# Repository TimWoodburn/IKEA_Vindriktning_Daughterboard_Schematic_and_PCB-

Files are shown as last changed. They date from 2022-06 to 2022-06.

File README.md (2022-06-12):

# IKEA_Vindriktning_Daughterboard_Schematic_and_PCB

## Prelude - design choices before this project.
After reading about the IKEA sensor in Hackaday <https://hackaday.com/2021/08/13/hacked-ikea-air-quality-sensor-gets-custom-pcb/> I embarked on implementing on my favourite Wifi connected microcontroller ESP8266 with a view to adding additional sensors.  My usual preference is to roll-my-own, but during my research I became aware of a couple of implementations that utilized Tasmota.  This is an ideal platform to satisfy this requirement.  Web front end, MQTT ready, community maintained and includes the peripherals I was interested in; namely BME280 and LDR and the Ikea particulate sensor.  

This project is an adoptation based on Lond's Hackaday.io project, https://hackaday.io/project/181195-ikea-vindriktning-pcb and
Catalin Sanda who provided their schematics, https://hackaday.io/project/184282-ikea-vindriktning-daughterboard  

Blakadder has a nice write up.  The Tasmota setup is applicable to this project https://blakadder.com/vindriktning-tasmota/

If you dont wish to use Tasmota, checkout Hypfer's implements decoding of the Ikea sensor directly https://github.com/Hypfer/esp8266-vindriktning-particle-sensor

## Project Details

This project adds BME280 and Light Dependent resistor and uses Catalin Sanda's Tasmota binary.

The project uses the following ESP8266 ports:
- GPIO 4 for the Ikea particulate sensor input
- GPIO 1 for FTDI TXD
- GPIO 3 for FTDI RXD
- GPIO 12 for I2C SCL
- GPIO 14 for I2C SDA
- ADC for LDR input

## IKEA Vindriktning Daughterboard Schematic

A slight modification of Catalin Sanda's design on <https://hackaday.io/project/184282-ikea-vindriktning-daughterboard> which adds an input for a light dependent resistor into the ADC.  I have also chosen to use different inputs.  I also added the Molex picoblade sockets as suggested by Lond's project <https://hackaday.io/project/181195-ikea-vindriktning-pcb>.  The looms were challenging to work with and took some time to get right.  The Molex picoblade connectors look beautiful, but the crimps are tiny and practice makes perfect in getting them right.  If I did this project from scratch again, I would purchase pre-crimped plugs and then terminate the tails.  I bought a cheap crimp tool so I am sure the experience with the £200 ratcheted Molex crimp tool is far better, but it was too expensive for this project.

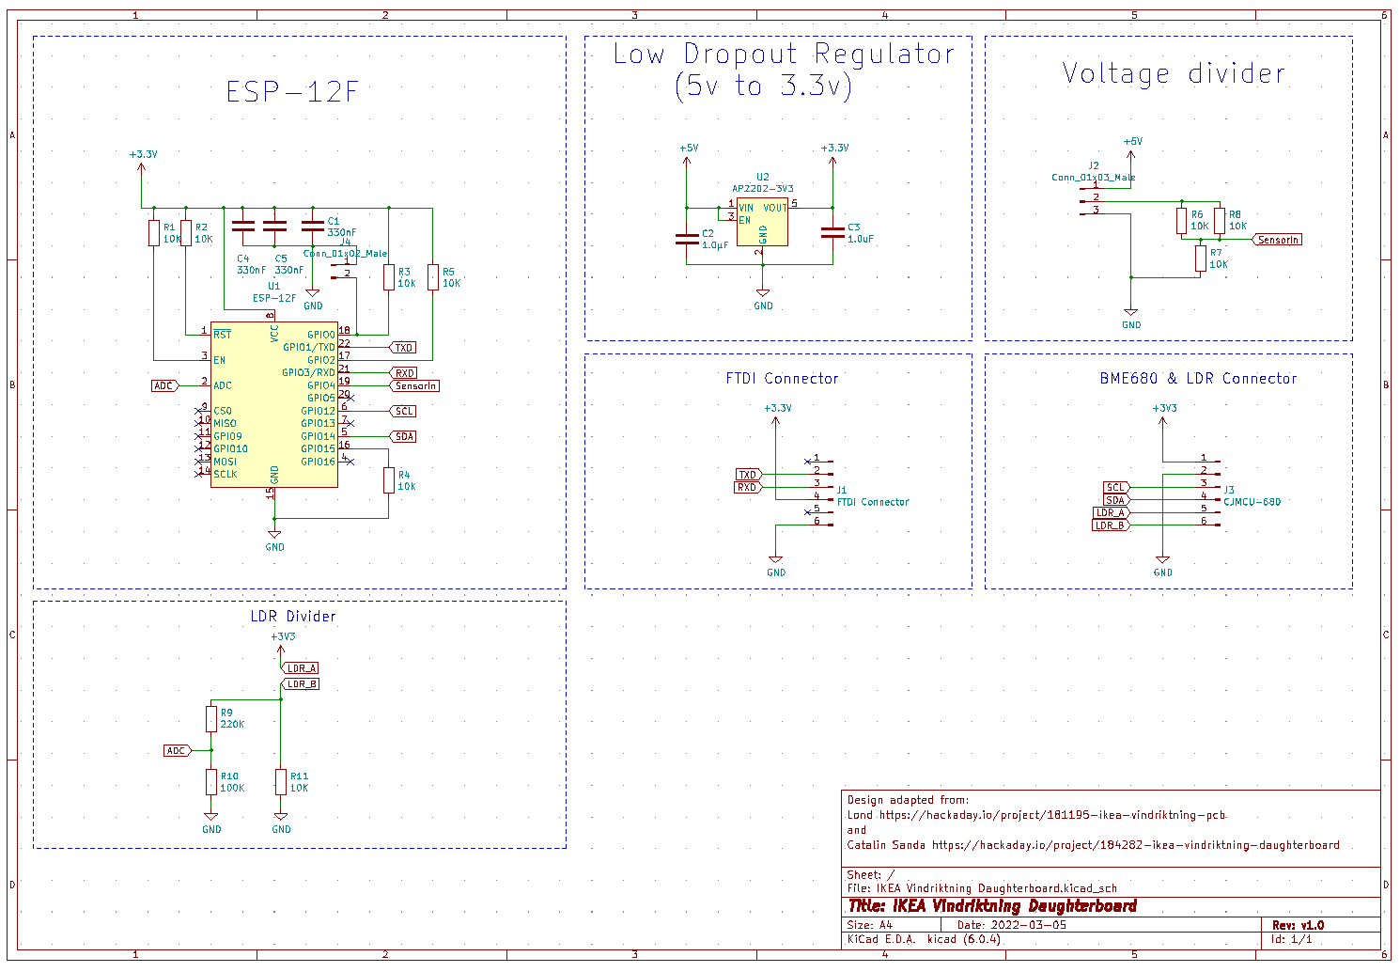
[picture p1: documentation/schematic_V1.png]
Schematic Schematic V1.0

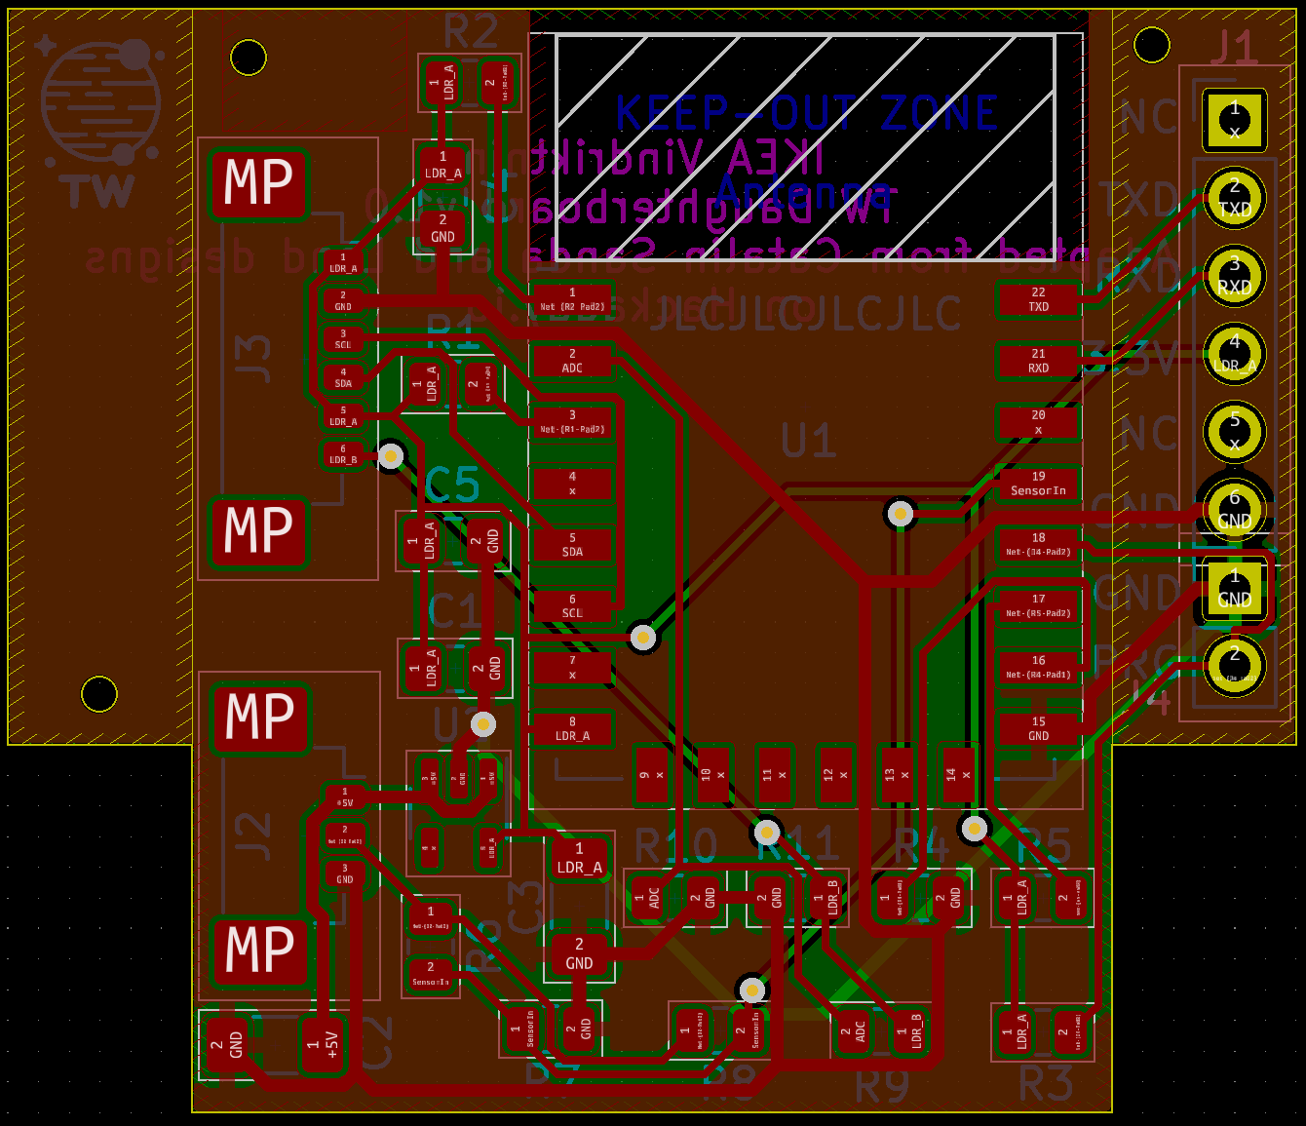
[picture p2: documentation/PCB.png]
PCB


## Modification of the IKEA Vindriktning PCB

The designers were very generous in making the board accessible to makers.  In order to use connect the daughterboard neatly, a 5 way Molex SMD socket should be soldered to the board (pictured on the LHS of the board).  As others have done in their solutions, it is possible to solder directly to the board.

The light dependent resistor is fitted to the fascia as pictured and terminals insulated.  I kept the BME280 loose to allow for placement away from the fascia in the other half of the enclosure.  
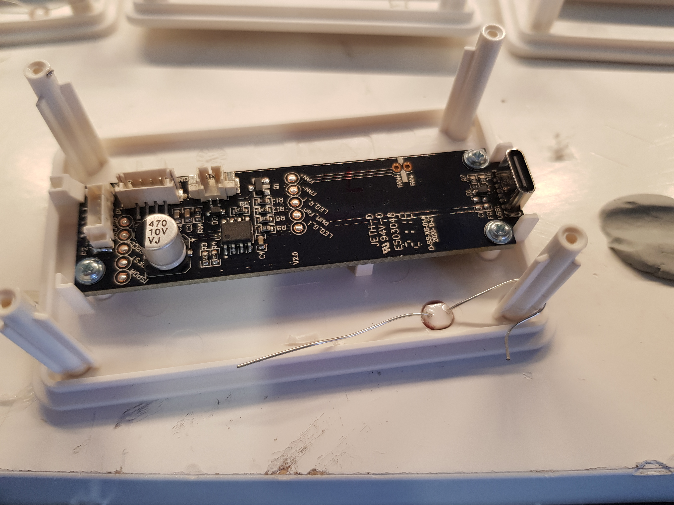
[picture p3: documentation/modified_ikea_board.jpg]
Modified Ikea board

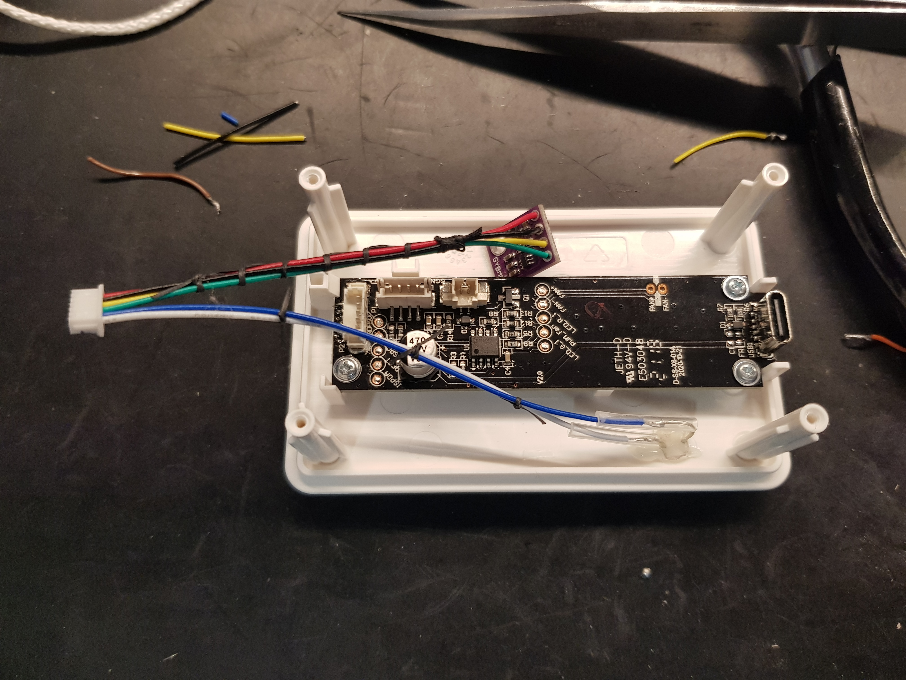
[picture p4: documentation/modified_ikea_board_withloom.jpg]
Modified Ikea board with loom


## Daughterboard

Pictured as received from JLCPCB.  Note R9 pictured reflects the BOM error which fitted a 2R2 resistor, rather than 220K0. The repo BOM has been corrected.
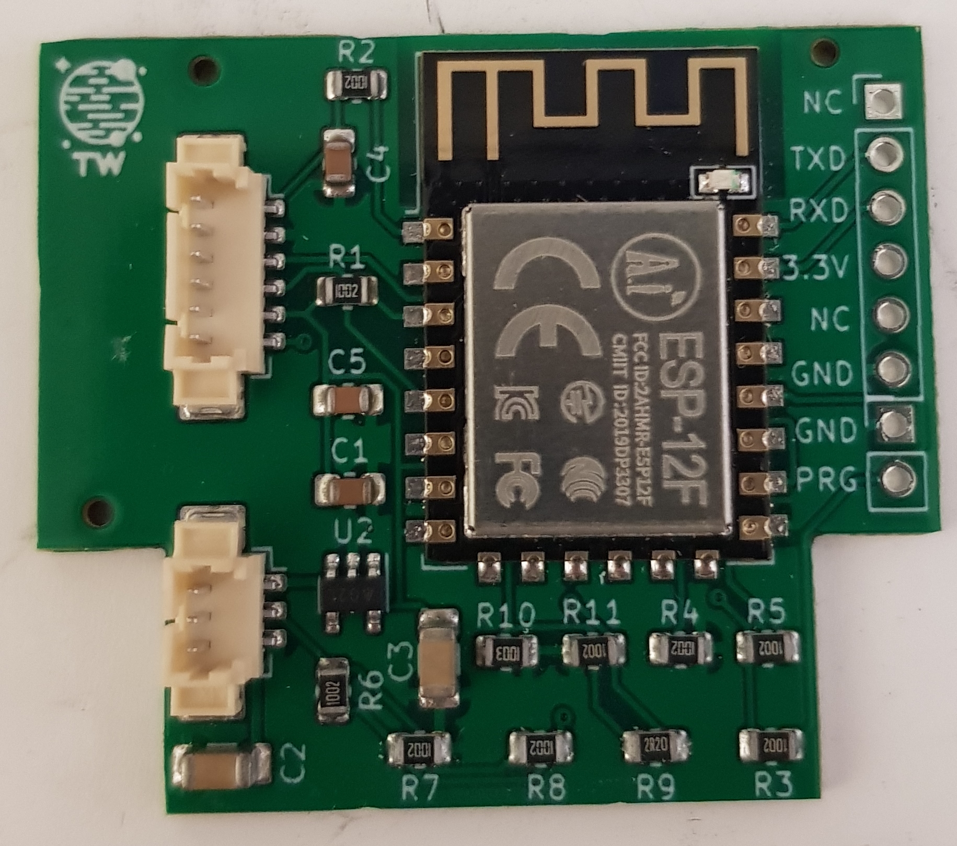
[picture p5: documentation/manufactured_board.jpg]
Final Assembled Board Final assembled board


I copied the Caralin's flashing method and will use the same method in future boards.  The PRG pin is shorted to ground away from the board.  I bought mine from AliExpress which seems to work quite well [LINK](https://www.aliexpress.com/item/1005001409579446.html)  I flashed the boards with Tazmotizer with the version that contains the Vindriktning peripheral.  Alternatively use [tasmota-allsensors unoffical build](https://github.com/tasmota/install/raw/main/firmware/unofficial/tasmota-allsensors.bin) although this is untested.  The version I used is within this repo.
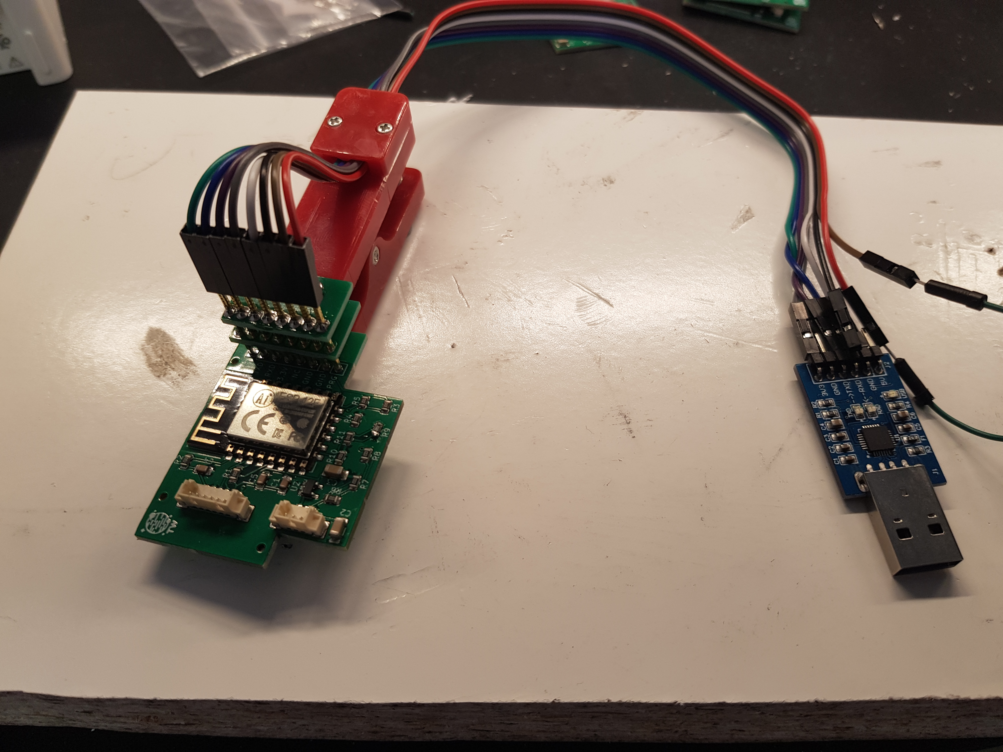
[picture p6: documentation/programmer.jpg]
Programming adaptor


The spring in the laced BME280 loom positions the board out of the way.  Once you have tested, you may wish to secure it.  The board itself slides behind the screw pillars.
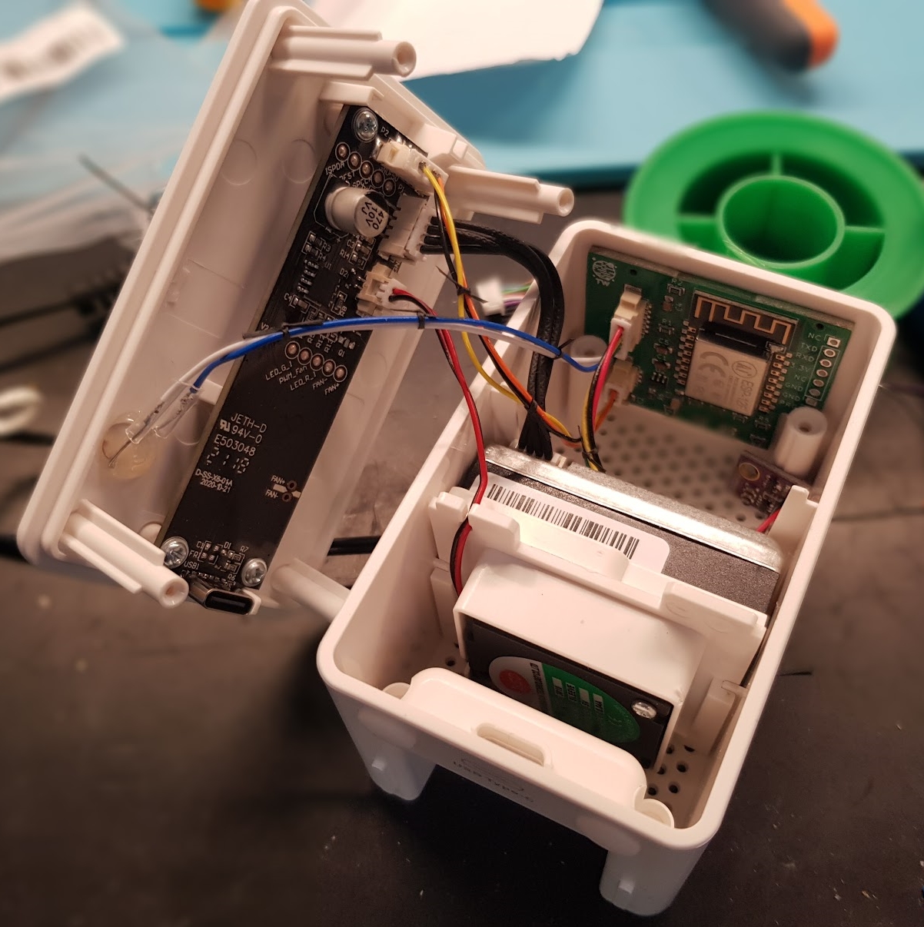
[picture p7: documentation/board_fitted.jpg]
Board fitted to Vindriktning


## Tasmota Setup 

Once fitted, configure the module as follows.
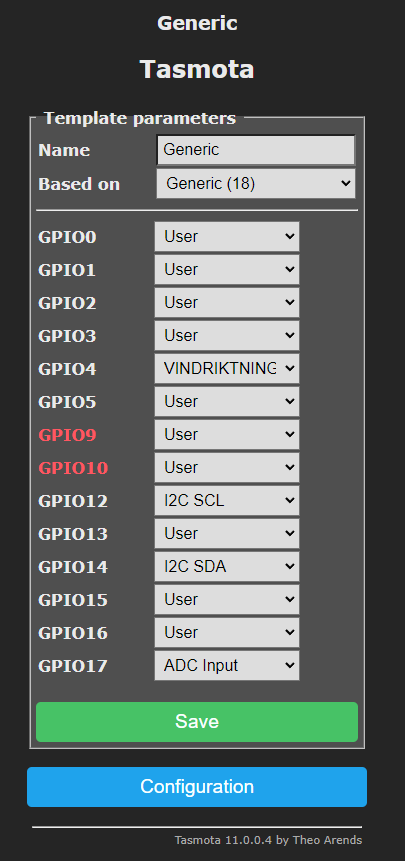
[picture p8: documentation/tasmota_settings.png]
Tasmota Settings


Which should generate a home page like this.
Tasmota Home Page TASMOTA home page

To change the device name, go to the "other options" page and set there.

## In use
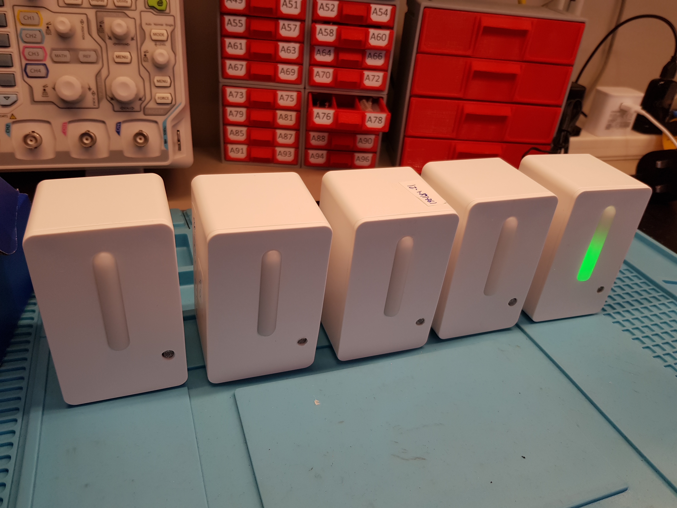
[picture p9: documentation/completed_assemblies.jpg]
Completed assemblies


I use mine with my other house sensors signalled with MQTT.  My MQTT setup uses Mosquitto and NODERED.  
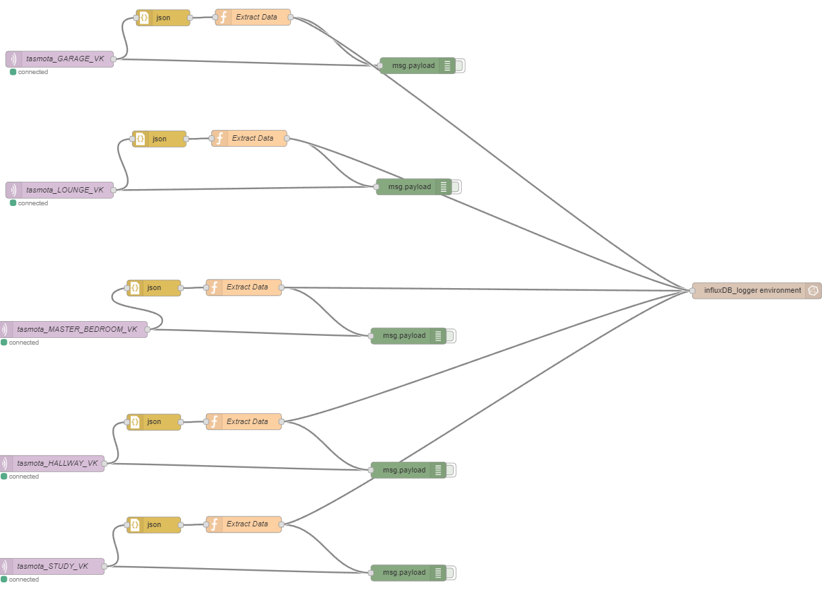
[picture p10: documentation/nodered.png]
NODE RED LAYOUT NODERED layout


The data is stored in an InfluxDB 3.x database and viewed on Grafana.  The garage peak is probably due to me sweeping up after completing this project!
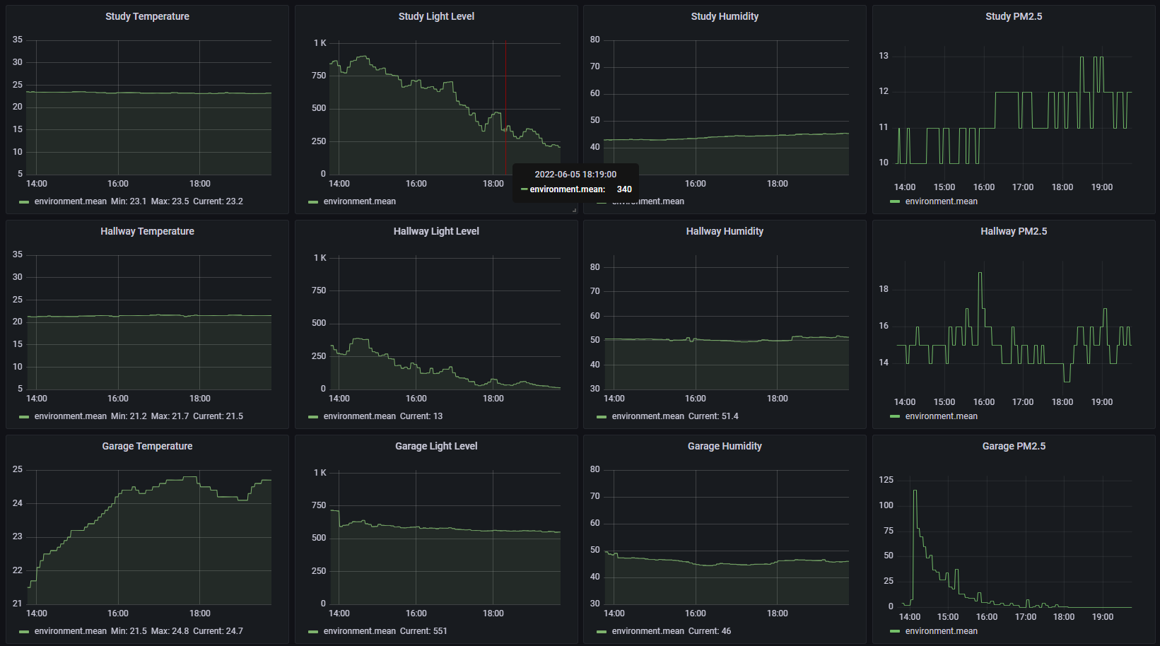
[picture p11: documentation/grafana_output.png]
Grafana Output


## How to order populated PCB with JLCPCB
[Phil's Lab - Kicad design and JLCPCB Assembly for ordering this board.](https://www.youtube.com/watch?v=C7-8nUU6e3E&t=9415s)
1. Go to [JLCPCB](https://jlcpcb.com/") and log in.
2. Click on "Instant quote".
3. Upload the zipped gerber.
4. Review the board parameters (you may click remove order number if you wish).
5. Click PCB assembly.
6. Click Tooling Holes "Added by Cuastomer" and agree the T&C if you are happy with them.
7. Click confirm.
8. Click "Add BOM File", browse for IKEA_Vindriktning_Daughterboard-TW_bom.xls file in the assembly directory.
9. Click "Add CPL", browse for IKEA_Vindriktning_Daughterboard-all-pos.xls file in the assembly directory.
10. Select Sensor/Controller/Precision Instrument/Temperature sensor" or similar in the description combobox, probably for customs declarations.
11. Check the matched part detail, especially the values and if they are in stock.  You may have to search for alternative parts if there are none in stock.  Check the footprints of alternatives.
12. Click next.
13. The review parts placement window will probably show incorrect rotation on some parts, this will be checked and corrected by JLCPCB.
14. Save to cart and order.

## Vindriktning Links  
[Catlalin Sanda Hackaday.io blog post](https://hackaday.io/project/184282-ikea-vindriktning-daughterboard)  
[Lond's Hackaday.io blog post](https://hackaday.io/project/181195-ikea-vindriktning-pcb)  
[Blakadder's IKEA Vindriktning air quality sensor running Tasmota](https://blakadder.com/vindriktning-tasmota/)  
[Hypfer/esp8266-vindriktning-particle-sensor](https://github.com/Hypfer/esp8266-vindriktning-particle-sensor)  
[Vccground implementation - #34 VINDRIKTNING | Modifying to the next level as Standalone / Home Assistant Connected Multi Sensor ](https://www.youtube.com/watch?v=BSLXqhjjSZI) includes a schematic of the Ikea board.  

## Other Links  
[Tasmota Home](https://tasmota.github.io/docs/)  
[tasmota-allsensors unoffical build](https://github.com/tasmota/install/raw/main/firmware/unofficial/tasmota-allsensors.bin)  
[Phil's Lab - Kicad design and JLCPCB Assembly for ordering this board.](https://www.youtube.com/watch?v=C7-8nUU6e3E&t=9415s)

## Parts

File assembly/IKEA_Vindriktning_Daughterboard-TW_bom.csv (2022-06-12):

Comment | Designator | Footprint | LCSC
330nF | C1,C4,C5 | Capacitor_SMD:C_0805_2012Metric_Pad1.18x1.45mm_HandSolder | C1775
1.0µF | C2 | Capacitor_SMD:C_1206_3216Metric_Pad1.33x1.80mm_HandSolder | C1848
1.0uF | C3 | Capacitor_SMD:C_1206_3216Metric_Pad1.33x1.80mm_HandSolder | C1848
FTDI Connector | J1 | Connector_PinHeader_2.54mm:PinHeader_1x06_P2.54mm_Vertical
Conn_01x03_Male | J2 | Connector_Molex:Molex_PicoBlade_53398-0371_1x03-1MP_P1.25mm_Vertical | C293633
CJMCU-680 | J3 | Connector_Molex:Molex_PicoBlade_53398-0671_1x06-1MP_P1.25mm_Vertical | C277393
Conn_01x02_Male | J4 | Connector_PinHeader_2.54mm:PinHeader_1x02_P2.54mm_Vertical
10K | R1,R2,R3,R4,R5,R6,R7,R8,R11 | Resistor_SMD:R_0805_2012Metric | C17414
100K | R10 | Resistor_SMD:R_0805_2012Metric | C149504
220K | R9 | Resistor_SMD:R_0805_2012Metric | C17556
ESP-12F | U1 | RF_Module:ESP-12E | Copy
AP2202-3V3 | U2 | Package_TO_SOT_SMD:SOT-23-5 | C150442

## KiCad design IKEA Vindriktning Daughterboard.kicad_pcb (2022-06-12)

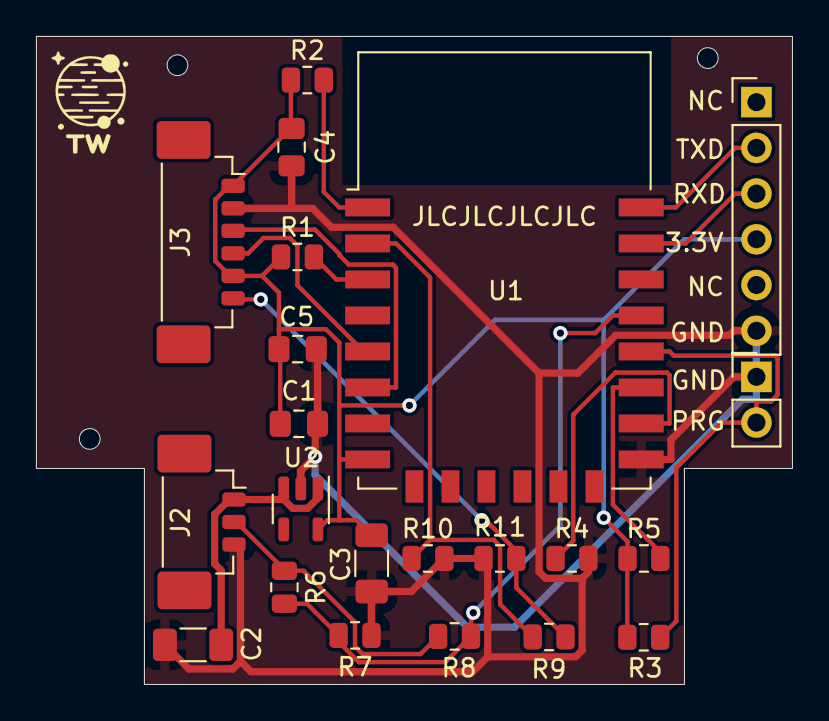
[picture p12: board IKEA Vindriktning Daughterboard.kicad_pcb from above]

Board: 2 copper layers, 42.0 x 36.0 mm, 22 parts (0 on the bottom side), 16 nets.

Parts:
C1, C4, C5: 330nF; C_0805_2012Metric_Pad1.18x1.45mm_HandSolder
C2: 1.0µF; C_1206_3216Metric_Pad1.33x1.80mm_HandSolder
C3: 1.0uF; C_1206_3216Metric_Pad1.33x1.80mm_HandSolder
J1: FTDI Connector; PinHeader_1x06_P2.54mm_Vertical
J2: Conn_01x03_Male; Molex_PicoBlade_53398-0371_1x03-1MP_P1.25mm_Vertical
J3: CJMCU-680; Molex_PicoBlade_53398-0671_1x06-1MP_P1.25mm_Vertical
J4: Conn_01x02_Male; PinHeader_1x02_P2.54mm_Vertical
R1, R2, R3, R4, R5, R6, R7, R8, R11: 10K; R_0805_2012Metric
R9: 220K; R_0805_2012Metric
R10: 100K; R_0805_2012Metric
U1: ESP-12F; ESP-12E
U2: AP2202-3V3; SOT-23-5

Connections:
+5V: C2.1, J2.1, U2.1 (VIN), U2.3 (EN)
ADC: R9.2, R10.1, U1.2 (ADC)
GND: C1.2, C2.2, C3.2, C4.2, C5.2, J1.6, J2.3, J3.2, J4.1, R4.2, R7.2, R10.2, R11.2, U1.15 (GND), U2.2 (GND)
LDR_A: C1.1, C3.1, C4.1, C5.1, J1.4, J3.1, J3.5, R1.1, R2.1, R3.1, R5.1, U1.8 (VCC), U2.5 (VOUT)
LDR_B: J3.6, R9.1, R11.1
unnamed: J2.2, R6.1, R8.1
unnamed: J4.2, R3.2, U1.18 (GPIO0)
unnamed: R1.2, U1.3 (EN)
unnamed: R2.2, U1.1 (~RST)
unnamed: R4.1, U1.16 (GPIO15)
unnamed: R5.2, U1.17 (GPIO2)
RXD: J1.3, U1.21 (GPIO3/RXD)
SCL: J3.3, U1.6 (GPIO12)
SDA: J3.4, U1.5 (GPIO14)
SensorIn: R6.2, R7.1, R8.2, U1.19 (GPIO4)
TXD: J1.2, U1.22 (GPIO1/TXD)
